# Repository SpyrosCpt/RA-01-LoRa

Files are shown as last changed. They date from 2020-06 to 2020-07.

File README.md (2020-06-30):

# RA-01-LoRa Dev Board

## Features
- Max 15V DC input
- 5V DC USB input
- CP2102 USB interface
- STM32F030RCT6
- 0.96" 128 x 32 OLED
- RA-01 LoRA Module
- LM35 Temperature Sensor
- AT93C46 EEPROM
- 4 Way DIP Switch
- 4 Push Buttons
- STM32 programming by SWD

## Firmware Example Provided
- Press Push Button 1 to Send LoRA Packet, you can change the data to send by editing TestLoraTransmit("packet to send")
- When not transmitting LoRA radio is in Receiver mode and will display any messages receievd
- Temperature Monitoring of LM35 will be displayed on OLED

## Hardware Version 1.1
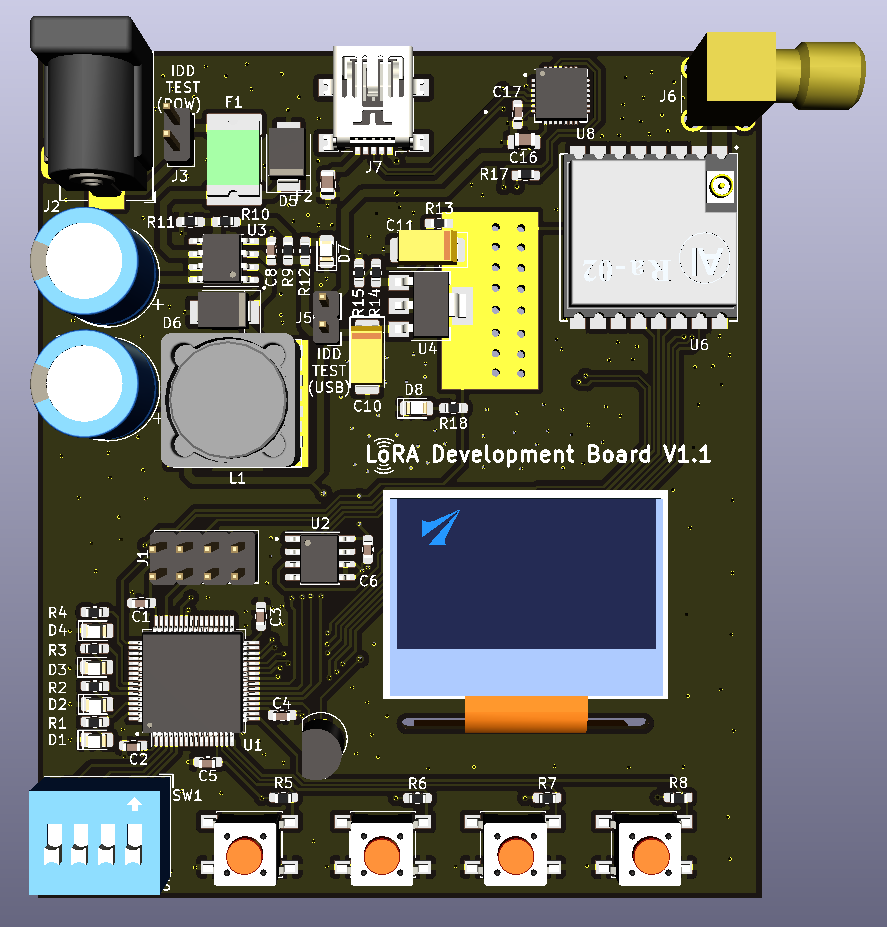
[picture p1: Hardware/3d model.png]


## Firmware Change Log
- Changed frequency down from 915Mhz to 433MHz
- Oled working
- LoRa working
- EEPROM working
- Temp Sensor

## Harware Change Log
- Removed USB protection IC
- Swapped TX and RX lines
- Grounded pin 16 + 17 on OLED connector
- Moved LM34 Vcc from 3.3V to 5V

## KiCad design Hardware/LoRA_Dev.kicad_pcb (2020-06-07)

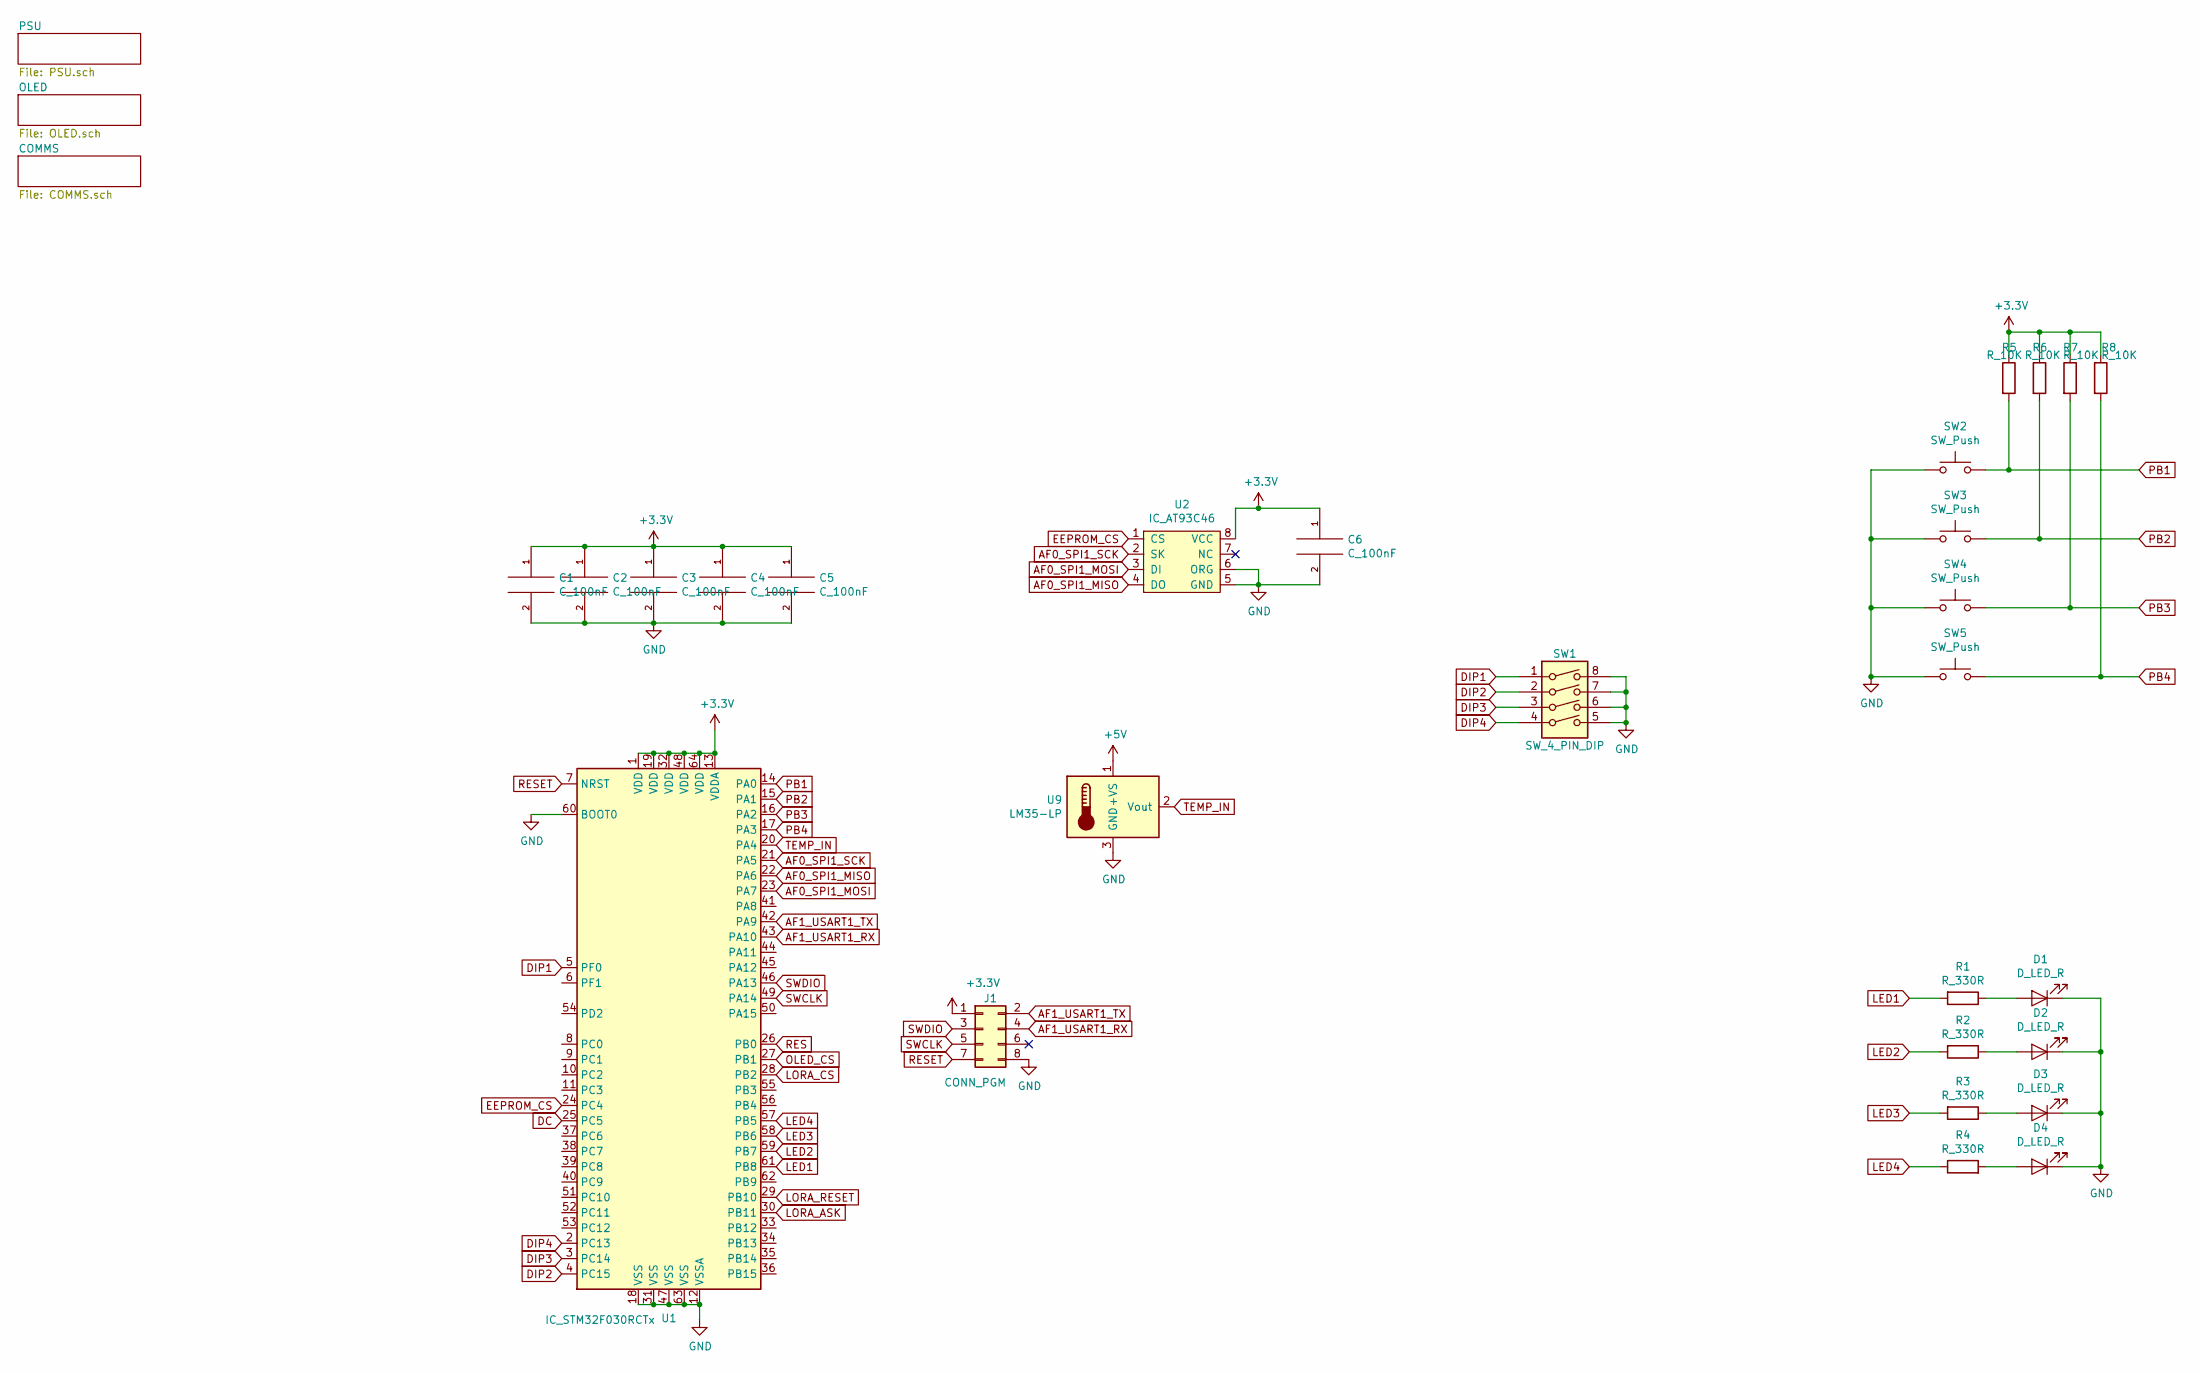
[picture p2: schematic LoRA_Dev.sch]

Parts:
C1, C2, C3, C4, C5, C6: C_100nF; C_0603_1608Metric_Pad1.05x0.95mm_HandSolder
D1, D2, D3, D4: D_LED_R; LED_0805_2012Metric_Pad1.15x1.40mm_HandSolder
J1: CONN_PGM; PinHeader_2x04_P2.54mm_Vertical
R1, R2, R3, R4: R_330R; R_0603_1608Metric_Pad1.05x0.95mm_HandSolder
R5, R6, R7, R8: R_10K; R_0603_1608Metric_Pad1.05x0.95mm_HandSolder
SW1: SW_4_PIN_DIP; SW_DIP_SPSTx04_Slide_9.78x12.34mm_W7.62mm_P2.54mm
SW2, SW3, SW4, SW5: SW_Push; SW_SPST_PTS645
U1: IC_STM32F030RCTx; LQFP-64_10x10mm_P0.5mm
U2: IC_AT93C46; SOIC-8_3.9x4.9mm_P1.27mm
U9: LM35-LP; TO-92

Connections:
+3V3: C1.1, C2.1, C3.1, C4.1, C5.1, C6.1, J1.1, R5.1, R6.1, R7.1, R8.1, U1.1 (VDD), U1.13 (VDDA), U1.19 (VDD), U1.32 (VDD), U1.48 (VDD), U1.64 (VDD), U2.8 (VCC); also elsewhere on the board
+5V: U9.1 (+VS); also elsewhere on the board
AF0_SPI1_MISO: U1.22 (PA6), U2.4 (DO); also elsewhere on the board
AF0_SPI1_MOSI: U1.23 (PA7), U2.3 (DI); also elsewhere on the board
AF0_SPI1_SCK: U1.21 (PA5), U2.2 (SK); also elsewhere on the board
AF1_USART1_RX: J1.4, U1.43 (PA10); also elsewhere on the board
AF1_USART1_TX: J1.2, U1.42 (PA9); also elsewhere on the board
DC: U1.25 (PC5); also elsewhere on the board
DIP1: SW1.1, U1.5 (PF0)
DIP2: SW1.2, U1.4 (PC15)
DIP3: SW1.3, U1.3 (PC14)
DIP4: SW1.4, U1.2 (PC13)
EEPROM_CS: U1.24 (PC4), U2.1 (CS)
GND: C1.2, C2.2, C3.2, C4.2, C5.2, C6.2, D1.1 (K), D2.1 (K), D3.1 (K), D4.1 (K), J1.8, SW1.5, SW1.6, SW1.7, SW1.8, SW2.1, SW3.1, SW4.1, SW5.1, U1.12 (VSSA), U1.18 (VSS), U1.31 (VSS), U1.47 (VSS), U1.60 (BOOT0), U1.63 (VSS), U2.5 (GND), U2.6 (ORG), U9.3 (GND); also elsewhere on the board
LED1: R1.2, U1.61 (PB8)
LED2: R2.2, U1.59 (PB7)
LED3: R3.2, U1.58 (PB6)
LED4: R4.1, U1.57 (PB5)
LORA_ASK: U1.30 (PB11); also elsewhere on the board
LORA_CS: U1.28 (PB2); also elsewhere on the board
LORA_RESET: U1.29 (PB10); also elsewhere on the board
unnamed: D1.2 (A), R1.1
unnamed: D2.2 (A), R2.1
unnamed: D3.2 (A), R3.1
unnamed: D4.2 (A), R4.2
OLED_CS: U1.27 (PB1); also elsewhere on the board
PB1: R5.2, SW2.2, U1.14 (PA0)
PB2: R6.2, SW3.2, U1.15 (PA1)
PB3: R7.2, SW4.2, U1.16 (PA2)
PB4: R8.2, SW5.2, U1.17 (PA3)
RES: U1.26 (PB0); also elsewhere on the board
RESET: J1.7, U1.7 (NRST)
SWCLK: J1.5, U1.49 (PA14)
SWDIO: J1.3, U1.46 (PA13)
TEMP_IN: U1.20 (PA4), U9.2 (Vout)

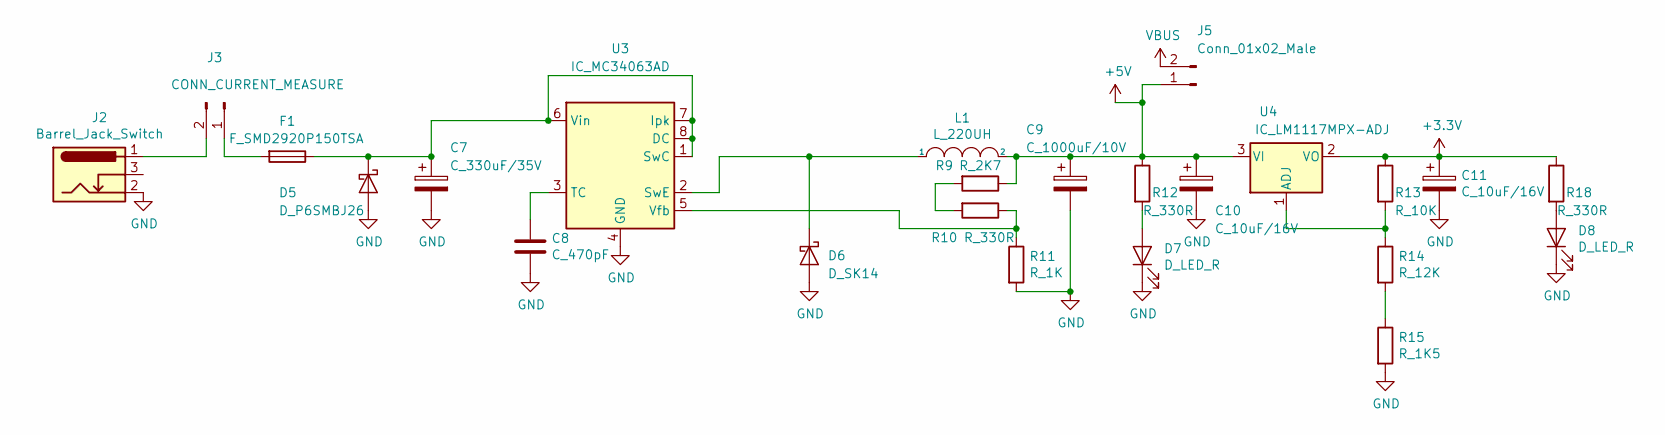
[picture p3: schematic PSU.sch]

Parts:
C7: C_330uF/35V; CP_Radial_D10.0mm_P5.00mm
C8: C_470pF; C_0603_1608Metric_Pad1.05x0.95mm_HandSolder
C9: C_1000uF/10V; CP_Radial_D10.0mm_P5.00mm
C10, C11: C_10uF/16V; CP_EIA-6032-28_Kemet-C_Pad2.25x2.35mm_HandSolder
D5: D_P6SMBJ26; D_SMB
D6: D_SK14; D_SMB
D7, D8: D_LED_R; LED_0805_2012Metric_Pad1.15x1.40mm_HandSolder
F1: F_SMD2920P150TSA; Fuse_2920_7451Metric_Pad2.10x5.45mm_HandSolder
J2: Barrel_Jack_Switch; BarrelJack_Horizontal
J3: CONN_CURRENT_MEASURE; PinHeader_2x01_P2.54mm_Vertical
J5: Conn_01x02_Male; PinHeader_1x02_P2.54mm_Vertical
L1: L_220UH; L_12x12mm_H8mm
R9: R_2K7; R_0603_1608Metric_Pad1.05x0.95mm_HandSolder
R10, R12, R18: R_330R; R_0603_1608Metric_Pad1.05x0.95mm_HandSolder
R11: R_1K; R_0603_1608Metric_Pad1.05x0.95mm_HandSolder
R13: R_10K; R_0603_1608Metric_Pad1.05x0.95mm_HandSolder
R14: R_12K; R_0603_1608Metric_Pad1.05x0.95mm_HandSolder
R15: R_1K5; R_0603_1608Metric_Pad1.05x0.95mm_HandSolder
U3: IC_MC34063AD; SOIC-8_3.9x4.9mm_P1.27mm
U4: IC_LM1117MPX-ADJ; SOT-223-3_TabPin2

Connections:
+3V3: C11.1, R13.1, R18.1, U4.2 (VO); also elsewhere on the board
+5V: C9.1, C10.1, J5.1, L1.2, R9.1, R12.1, U4.3 (VI); also elsewhere on the board
GND: C7.2, C8.2, C9.2, C10.2, C11.2, D5.2 (A), D6.2 (A), D7.1 (K), D8.1 (K), J2.2, R11.2, R15.2, U3.4 (GND); also elsewhere on the board
unnamed: C7.1, D5.1 (K), F1.1, U3.1 (SwC), U3.6 (Vin), U3.7 (Ipk), U3.8 (DC)
unnamed: C8.1, U3.3 (TC)
unnamed: D6.1 (K), L1.1, U3.2 (SwE)
unnamed: D7.2 (A), R12.2
unnamed: D8.2 (A), R18.2
unnamed: F1.2, J3.1
unnamed: J2.1, J3.2
unnamed: R10.1, R11.1, U3.5 (Vfb)
unnamed: R9.2, R10.2
unnamed: R13.2, R14.1, U4.1 (ADJ)
unnamed: R14.2, R15.1
VBUS: J5.2; also elsewhere on the board

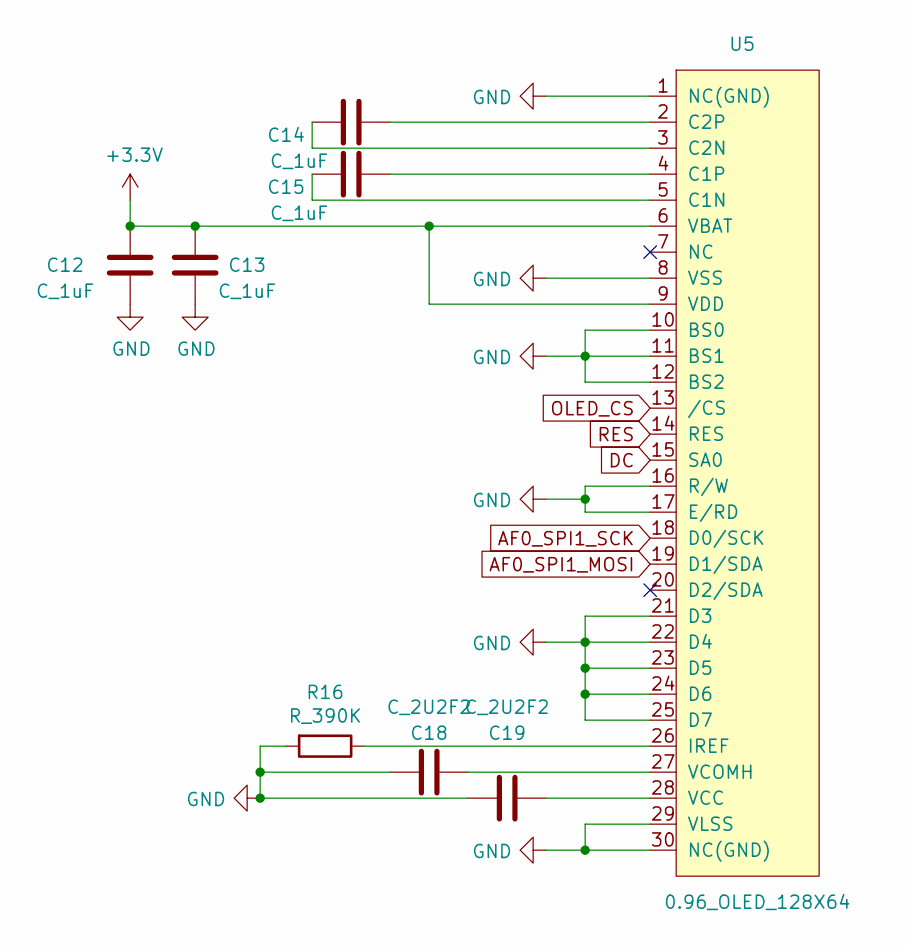
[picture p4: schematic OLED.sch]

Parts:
C12, C13, C14, C15: C_1uF; C_0805_2012Metric_Pad1.15x1.40mm_HandSolder
C18, C19: C_2U2F2; C_0805_2012Metric_Pad1.15x1.40mm_HandSolder
R16: R_390K; R_0603_1608Metric_Pad1.05x0.95mm_HandSolder
U5: 0.96_OLED_128X64; 0.96_OLED

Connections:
+3V3: C12.2, C13.2, U5.6 (VBAT), U5.9 (VDD); also elsewhere on the board
AF0_SPI1_MOSI: U5.19 (D1/SDA); also elsewhere on the board
AF0_SPI1_SCK: U5.18 (D0/SCK); also elsewhere on the board
DC: U5.15 (SA0); also elsewhere on the board
GND: C12.1, C13.1, C18.1, C19.1, R16.2, U5.1 (NC(GND)), U5.8 (VSS), U5.10 (BS0), U5.11 (BS1), U5.12 (BS2), U5.16 (R/W), U5.17 (E/RD), U5.21 (D3), U5.22 (D4), U5.23 (D5), U5.24 (D6), U5.25 (D7), U5.29 (VLSS), U5.30 (NC(GND)); also elsewhere on the board
unnamed: C14.1, U5.2 (C2P)
unnamed: C14.2, U5.3 (C2N)
unnamed: C15.1, U5.4 (C1P)
unnamed: C15.2, U5.5 (C1N)
unnamed: C18.2, U5.27 (VCOMH)
unnamed: C19.2, U5.28 (VCC)
unnamed: R16.1, U5.26 (IREF)
OLED_CS: U5.13 (/CS); also elsewhere on the board
RES: U5.14 (RES); also elsewhere on the board

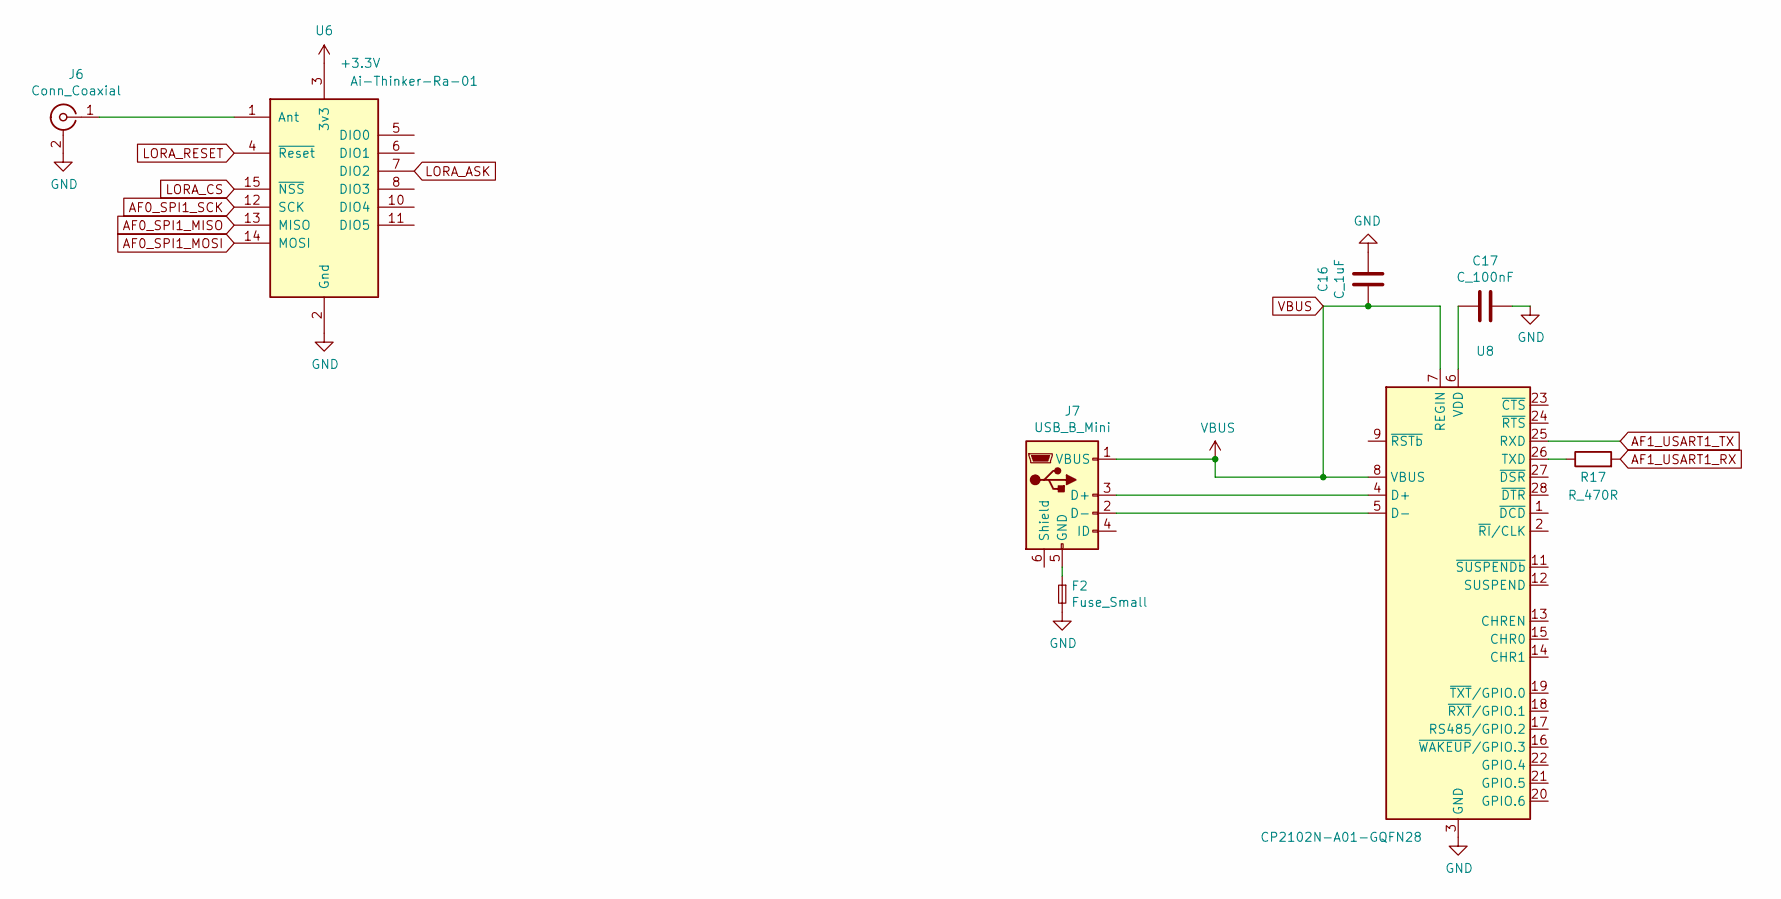
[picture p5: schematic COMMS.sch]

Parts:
C16: C_1uF; C_0805_2012Metric_Pad1.15x1.40mm_HandSolder
C17: C_100nF; C_0603_1608Metric_Pad1.05x0.95mm_HandSolder
F2: Fuse_Small; C_0805_2012Metric
J6: Conn_Coaxial; SMA_Amphenol_132134_Vertical
J7: USB_B_Mini; USB_Mini-B_Lumberg_2486_01_Horizontal
R17: R_470R; R_0603_1608Metric_Pad1.05x0.95mm_HandSolder
U6: Ai-Thinker-Ra-01; Ai-Thinker-Ra-01-LoRa
U8: CP2102N-A01-GQFN28; QFN-28-1EP_5x5mm_P0.5mm_EP3.35x3.35mm

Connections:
+3V3: U6.3 (3v3); also elsewhere on the board
AF0_SPI1_MISO: U6.13 (MISO); also elsewhere on the board
AF0_SPI1_MOSI: U6.14 (MOSI); also elsewhere on the board
AF0_SPI1_SCK: U6.12 (SCK); also elsewhere on the board
AF1_USART1_RX: R17.2; also elsewhere on the board
AF1_USART1_TX: U8.25 (RXD); also elsewhere on the board
GND: C16.1, C17.1, F2.2, J6.2 (Ext), U6.2 (Gnd), U6.9 (Gnd), U6.16 (Gnd), U8.3 (GND), U8.29 (GND); also elsewhere on the board
LORA_ASK: U6.7 (DIO2); also elsewhere on the board
LORA_CS: U6.15 (~NSS); also elsewhere on the board
LORA_RESET: U6.4 (~Reset); also elsewhere on the board
unnamed: C17.2, U8.6 (VDD)
unnamed: F2.1, J7.5 (GND)
unnamed: J6.1 (In), U6.1 (Ant)
unnamed: J7.2 (D-), U8.5 (D-)
unnamed: J7.3 (D+), U8.4 (D+)
unnamed: R17.1, U8.26 (TXD)
VBUS: C16.2, J7.1 (VBUS), U8.7 (REGIN), U8.8 (VBUS); also elsewhere on the board

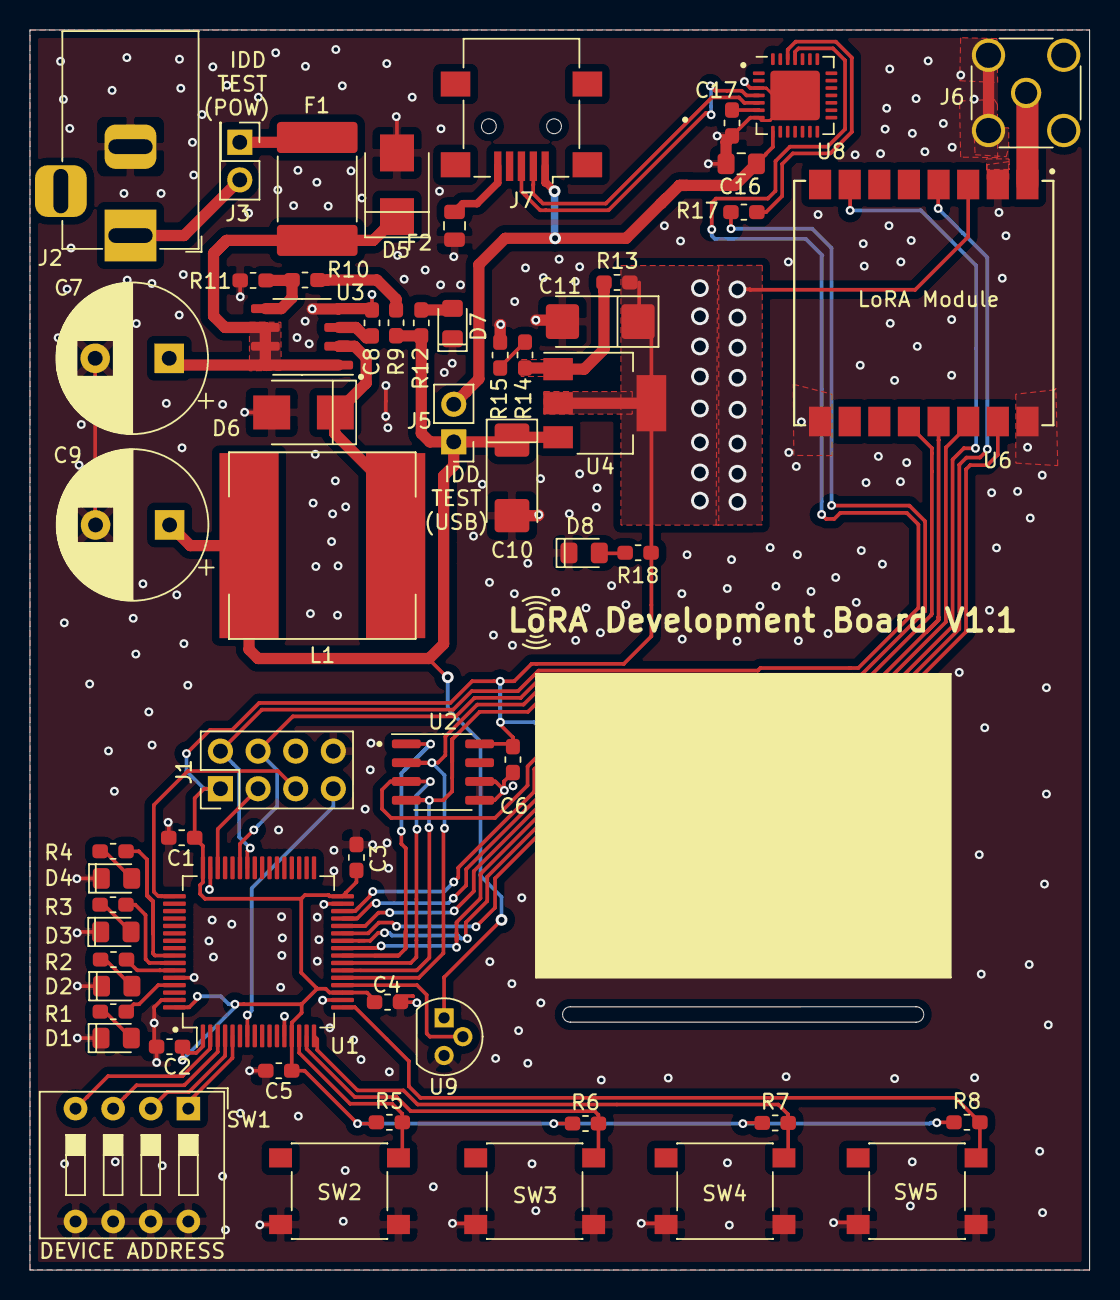
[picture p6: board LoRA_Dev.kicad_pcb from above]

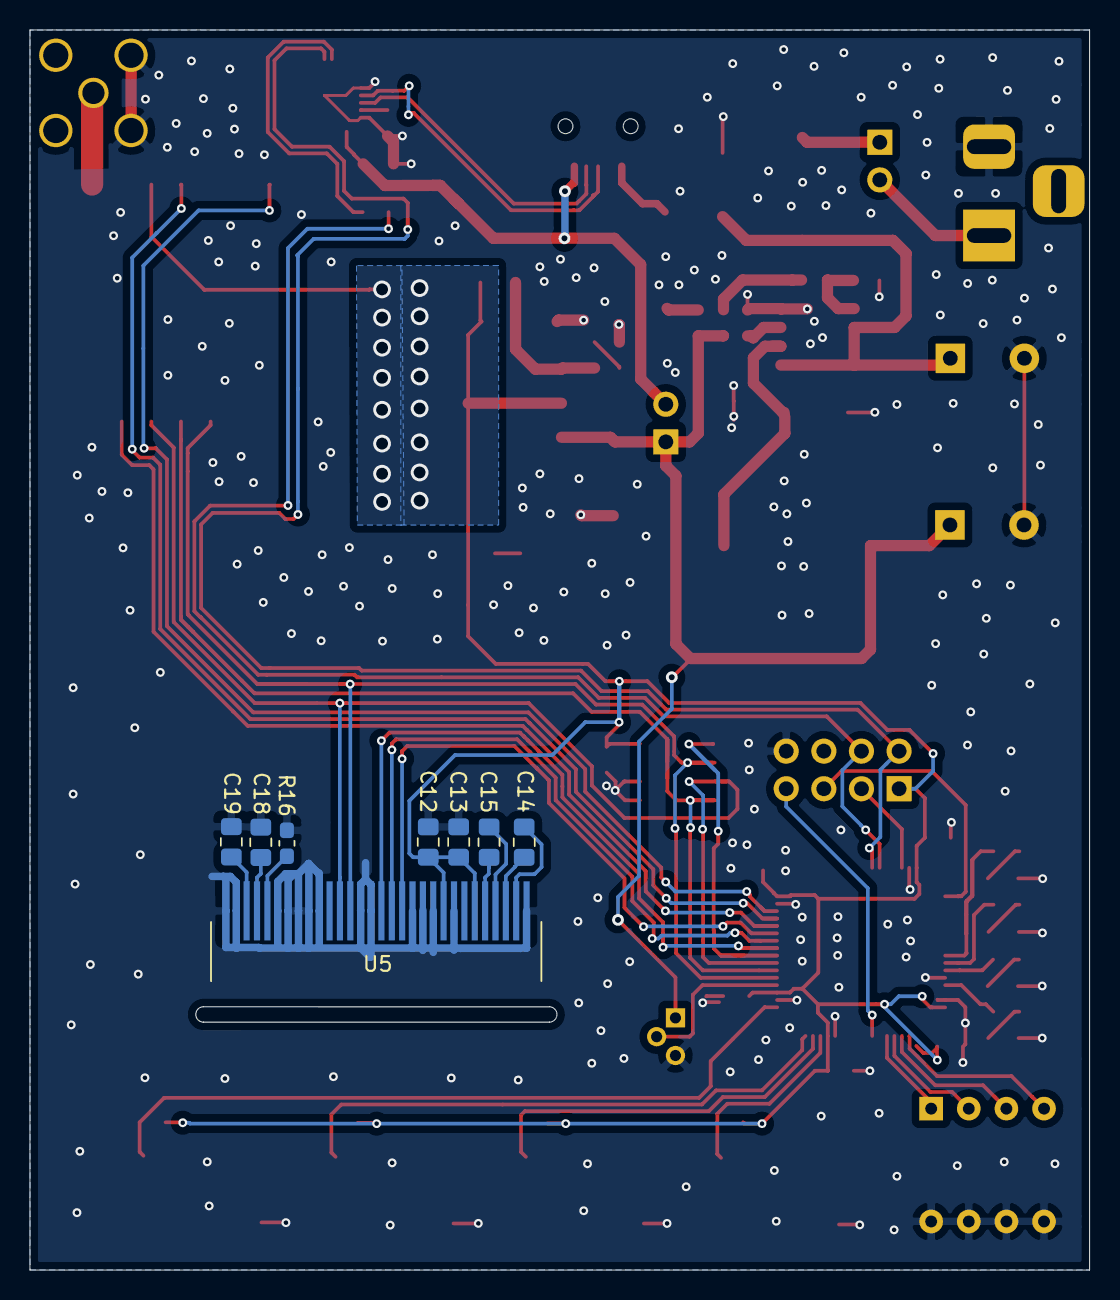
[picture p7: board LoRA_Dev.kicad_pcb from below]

Board: 2 copper layers, 71.5 x 83.7 mm, 67 parts (8 on the bottom side), 60 nets.

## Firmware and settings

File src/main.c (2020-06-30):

#include "preprocessor.h"

#define ADC_TEMPERATURE_CH ADC_CHSELR_CHSEL4

/****************************************/
/***************PROTOTYPES***************/
/****************************************/
void delaymms(int ms);
void delayuus(int us);
void getTemp(void);
void GetDeviceAddress(void);
UI16 GetAnalogVal(UI8 ch);
void GetVddVal(void);
UI16 Get_ADC_Val( void ); 
void DisableADC(void);
void EnableADC(void);
/****************************************/
/***********END OF PROTOTYPES************/
/****************************************/

/****************************************/
/************GLOBAL VARIABLES************/
/****************************************/
static __IO uint32_t systick=0;
volatile UI32 MILLISECS=0;
UI32 adcraw = 0;
UI32 Vdd = 0;
UI16 VddCal = 0;
UI32 TempVdd = 0;
__IO UI16 adcval = 0;
UI16 TemperatureTimer = 0;
UI16 AddressTimer = 0;

/****************************************/
/**********GLOBAL VARIABLES END**********/
/****************************************/

/**
	* @brief 	This is the systick interrupt handler, it fires every 10uS
	* @param 	None
	*	@retval None
	*/
void SysTick_Handler( void )
{
   if( systick ) systick--;
	 if( MILLISECS ) MILLISECS--;
}

/**
* @brief 	This function delays for x microseconds (note: resolution is 10uS)
	* @param 	us - time to wait in us
	*	@retval None
	*/
void delayuus(int us)
{
	systick = us;
	
	while(systick) ;
}

/**
	* @brief 	This function delays for x milliseconds
	* @param 	ms - time to wait in ms
	*	@retval None
	*/
void delaymms(int ms)
{
	MILLISECS = ms*100;
	while(MILLISECS) ;
}

/**
	* @brief 	This is the Timer 3 interrupt handler 
	* @param 	None
	*	@retval None
	*/
void TIM3_IRQHandler( void )
{
	volatile UI8 i;
	if( TIM3->SR & TIM_SR_UIF ) 					/* If UIF flag is set */
  {
		TIM3->SR &= ~TIM_SR_UIF; 					/* Clear UIF flag */
		
		if(TemperatureTimer) TemperatureTimer--;
		if(AddressTimer) AddressTimer--;
  }
}

/**
	* @brief 	This is the Timer 17 Interrupt 
	* @param 	None
	*	@retval None
	*/
void TIM17_IRQHandler( void )
{
if( TIM17->SR & TIM_SR_UIF ) 					/* If UIF flag is set */
 {
		TIM17->SR &= ~TIM_SR_UIF; 					/* Clear UIF flag */
  }
}

/**
	* @brief 	This function enables the ADC
	* @param 	None
	*	@retval None
	*/
void EnableADC(void)
{
	/* (1) Clear the ADRDY bit */
	/* (2) Enable the ADC */
	/* (3) Wait until ADC ready */
	ADC1->ISR |= ADC_ISR_ADRDY; /* (1) */
	ADC1->CR |= ADC_CR_ADEN; /* (2) */
	if ((ADC1->CFGR1 & ADC_CFGR1_AUTOFF) == 0)
	{
		while ((ADC1->ISR & ADC_ISR_ADRDY) == 0) /* (3) */
		{
		/* For robust implementation, add here time-out management */
		}
	}
}

/**
	* @brief 	This function disables the ADC
	* @param 	none		  
	* @retval none
	*/
void DisableADC(void)
{
	/* (1) Ensure that no conversion on going */
	/* (2) Stop any ongoing conversion */
	/* (3) Wait until ADSTP is reset by hardware i.e. conversion is stopped */
	/* (4) Disable the ADC */
	/* (5) Wait until the ADC is fully disabled */
	if ((ADC1->CR & ADC_CR_ADSTART) != 0) /* (1) */
	{
		ADC1->CR |= ADC_CR_ADSTP; /* (2) */
	}
	while ((ADC1->CR & ADC_CR_ADSTP) != 0) /* (3) */
	{
	/* For robust implementation, add here time-out management */
	}
	ADC1->CR |= ADC_CR_ADDIS; /* (4) */
	while ((ADC1->CR & ADC_CR_ADEN) != 0) /* (5) */
	{
	/* For robust implementation, add here time-out management */
	}
}

/**
	* @brief 	This function gets 60 values from the ADC and takes an average of them
	* @param 	None
	*	@retval Val16 - the averaged ADC value
	*/
UI16 Get_ADC_Val( void ) 
{ 
	UI8 samples = 0;                					    /* Each sample takes 1uS so we should get this over and done with in about 100uS */
	UI8 NumSamples = 60;
	UI32 adcreg=0;
	UI16 Val16;
	
	ADC1->CR |= ADC_CR_ADSTART;                 /* Start conversion */
	for( samples = 0; samples < NumSamples; samples++ )   /* Take 5 samples and add them together */
	{
		
		while( ( ADC1->ISR & ADC_ISR_EOC ) == 0 );  /* Wait for conversion to finish */
		
		adcreg += ADC1->DR;								        /* Get value from ADC data reg */
	}
	adcreg/=NumSamples;											    /* Get an average off all the samples */	
	Val16=adcreg;
		
	return Val16;

}

/**
	* @brief 	This function gets the actual value of Vdd using the stored calibration value
	* @param 	None
	*	@retval None
	*/
void GetVddVal(void)
{
	adcraw = 0;

	DisableADC();
	ADC1->CHSELR = 0x00000000;
	ADC1->CHSELR |= ADC_CHSELR_CHSEL17;                         /* Set ADC channel to Vref (CH17) */
	EnableADC();
	
	adcraw = Get_ADC_Val();

	Vdd = 3300UL * (*VREFINT_CAL) / adcraw;         /*Calculate actual Vdd value*/
	
	PrintfP("\nVdd = %d", Vdd);
	PrintfP("\nADC = %d", adcraw);

	if(Vdd>3500) Vdd=3300; //sanity                 /* Will sanitize if values are wonky */
	if(Vdd<3000) Vdd=3300;
	
}

/**
	* @brief 	This function sets and enables an analog channel and returns an ADC value from the channel
	* @param 	ch - channel to set
	*	@retval adcval - ADC value to return
	*/
UI16 GetAnalogVal(UI8 ch)
{
	adcval = 0;

	DisableADC();
	
	ADC1->CHSELR = 0x00000000;
	ADC1->CHSELR |= ch;                         /* Set ADC channel to Vref (CH17) */

	EnableADC();
	
	adcval = Get_ADC_Val();

	return adcval;
}

/**
	* @brief 	This function reads the position from the DIP switch and returns the value as an address
	* @param 	None
	*	@retval None
	*/
void GetDeviceAddress(void)
{
	UI8 DIPS[4] = {0,0,0,0};
	UI8 Address = 0;
	UI8 i = 0;
	
	if(!AddressTimer)
	{
		if(DIP0_READ() == 0) DIPS[3] = 1;
		if(DIP1_READ() == 0) DIPS[2] = 1;
		if(DIP2_READ() == 0) DIPS[1] = 1;
		if(DIP3_READ() == 0) DIPS[0] = 1;
		
		for(i = 0; i < 4; i++)
		{
			if(DIPS[i] == 1) Address |= (1<<i);
		}
		PrintOLED(0,0, "Address = %d", Address);
		AddressTimer = 100;
	}
}

/**
	* @brief 	This function gets a value from the LM35 or LM34 sensor (choose this in preprocessor.h)
	* @param 	None
	*	@retval None
	*/
void getTemperature(void)
{
	UI32 temp = 0;
	float temp2 = 0;
	
	if(TemperatureTimer == 0)
	{
		temp = GetAnalogVal(ADC_TEMPERATURE_CH);
		
		#if (TEMP_SENSOR == LM34)
		temp2 = temp*0.088;
		temp2 -= 32;
		temp2 *= 0.55555;
		#else 
		temp2 = (temp*Vdd);
		temp2 /= 4095;
		temp2/=10;
		#endif
		
		PrintOLED(0, 6, "Temp = %dC", (UI16)temp2);
		
		TemperatureTimer = 100;
	}
}

int main( void )
{	
	Setup();                          																			 /* Setup the hardware and peripherals */  
	
	while(1)
	{
		if(PB0_READ() == 0) TestLoRaTransmitter("Hello World"); /* Send out a packet */
	  
		getTemperature();                                              /* Get value from temperature sensor */
		GetDeviceAddress();                                     /* Check the DIP switches */
		TestLoRaReceiver();                                     /* Check and see if any incomming packets */
	}
}

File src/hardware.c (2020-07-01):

#include "preprocessor.h"

/**
	* @brief 	This function sets up a GPIO
	* @param 	*PORT - the port (GPIOA, GPIOB etc)
	*         pin - pin to use 0 - 15
	*					direction - INPUT or OUTPUT
	*					type - PushPull, OpenDrain
	*					speed - LoSpeed, MedSpeed, HiSpeed
	*					pull - PullUp, PullDwn, NoPull
	*					state - SET, RESET, NONE
	*	@retval None
	*/
void Set_Pin( GPIO_TypeDef * PORT, uint8_t pin, uint8_t direction, uint8_t type, uint8_t speed, uint8_t pull, uint8_t state )
{
	Set_Mode( PORT, pin, direction );
	Set_Type( PORT, pin, type );
	Set_Speed( PORT, pin, speed );
	Set_Pull( PORT, pin, pull );
	
	if( state == 1 ) PORT->BSRR |= ( 1 << pin );
	else if( state == 2 ) PORT->BRR |= ( 1 << pin );
}
void Set_Mode( GPIO_TypeDef * PORT, uint8_t pin, uint8_t direction ) 
{
	PORT->MODER |= ( direction<< ( pin * 2 ) );
}

void Set_Type( GPIO_TypeDef * PORT, uint8_t pin, uint8_t type )
{
	PORT->OTYPER |= ( type<<pin );
}

void Set_Speed(GPIO_TypeDef * PORT, uint8_t pin, uint8_t speed )
{
	PORT->OSPEEDR |= ( speed<<( pin * 2 ) );
}

void Set_Pull(GPIO_TypeDef * PORT, uint8_t pin, uint8_t pull )
{
	PORT->PUPDR |= ( pull<< ( pin * 2 ) );
}

/**
	* @brief 	This function sets up the GPIO
	* @param 	None
	*	@retval None
	*/
void Ports_Setup( void )
{
	Set_Pin(GPIOB,  5, OUTPUT, PushPull, HiSpeed, NoPull, SET);
	Set_Pin(GPIOB,  6, OUTPUT, PushPull, HiSpeed, NoPull, SET);
	Set_Pin(GPIOB,  7, OUTPUT, PushPull, HiSpeed, NoPull, SET);
	Set_Pin(GPIOB,  8, OUTPUT, PushPull, HiSpeed, NoPull, SET);

	Set_Pin(GPIOA,  0, INPUT, PushPull, HiSpeed, NoPull, NONE);
	Set_Pin(GPIOA,  1, INPUT, PushPull, HiSpeed, NoPull, NONE);
	Set_Pin(GPIOA,  2, INPUT, PushPull, HiSpeed, NoPull, NONE);
	Set_Pin(GPIOA,  3, INPUT, PushPull, HiSpeed, NoPull, NONE);
	
	Set_Pin(GPIOC,  13, INPUT, PushPull, HiSpeed, PullUp, NONE);
	Set_Pin(GPIOC,  14, INPUT, PushPull, HiSpeed, PullUp, NONE);
	Set_Pin(GPIOC,  15, INPUT, PushPull, HiSpeed, PullUp, NONE);
	Set_Pin(GPIOF,  0, INPUT, PushPull, HiSpeed, PullUp, NONE);
	
	Set_Pin(GPIOC,  4, OUTPUT, PushPull, HiSpeed, NoPull, RESET); //EEPROM_CS
	
	Set_Pin(GPIOA,  5, OUTPUT, PushPull, HiSpeed, NoPull, RESET); //CLK
	Set_Pin(GPIOA,  6, INPUT, PushPull, HiSpeed, NoPull, NONE);   //MISO
	Set_Pin(GPIOA,  7, OUTPUT, PushPull, HiSpeed, NoPull, RESET); //MOSI*/
	
	Set_Pin(GPIOB,  1, OUTPUT, PushPull, HiSpeed, NoPull, SET); //OLED_CS
	Set_Pin(GPIOC,  5, OUTPUT, PushPull, HiSpeed, NoPull, NONE); //OLED_DC
	Set_Pin(GPIOB,  0, OUTPUT, PushPull, HiSpeed, NoPull, SET); //OLED_RESET
	
	Set_Pin(GPIOB,  2, OUTPUT, PushPull, HiSpeed, NoPull, SET); //LORA_CS
	Set_Pin(GPIOB,  11, OUTPUT, PushPull, HiSpeed, NoPull, RESET); //LORA_CS
	Set_Pin(GPIOB,  10, OUTPUT, PushPull, HiSpeed, NoPull, SET); //LORA_RESET
}

/**
	* @brief 	This function sets up the Timer3 (1ms resolution)
	* @param 	None
	*	@retval None
	*/
void TIM3_Setup(void)//1ms resolution
{
	RCC->APB1ENR |= RCC_APB1ENR_TIM3EN;
	TIM3->PSC = (uint16_t) 24000 - 1;//23999;	        // Set prescaler to 24 000 (PSC + 1)
	TIM3->ARR = (uint16_t) 2 - 1;	          // Auto reload value 1000
	TIM3->DIER = TIM_DIER_UIE; // Enable update interrupt (timer level)
	TIM3->CR1 |= TIM_CR1_CEN;   // Enable timer
	NVIC_EnableIRQ( TIM3_IRQn ); // Enable interrupt from TIM3 (NVIC level)
}

/**
	* @brief 	This function sets up the Timer17 (10us resolution)
	* @param 	None
	*	@retval None
	*/
void TIM17_Setup(void)//10us resolution
{
	RCC->APB2ENR |= RCC_APB2ENR_TIM17EN;
	TIM17->PSC = (uint16_t) 8 - 1;//23999;	        // Set prescaler to 24 000 (PSC + 1)
	TIM17->ARR = (uint16_t) 2 - 1;//10-1;//10 - 1;	          // Auto reload value 1000
	TIM17->DIER = TIM_DIER_UIE; // Enable update interrupt (timer level)
	TIM17->CR1 &= ~TIM_CR1_CEN;   // Enable timer
	NVIC_EnableIRQ( TIM17_IRQn ); // Enable interrupt from TIM3 (NVIC level)
}

/**
	* @brief 	This function sets up systick (10uS)
	* @param 	None
	*	@retval None
	*/
void SysTick_Init(void) 
{
	/****************************************
	 *SystemFrequency/1000      1ms         *
	 *SystemFrequency/100000    10us        *
	 *SystemFrequency/1000000   1us         *
	 *****************************************/
	while ((SysTick_Config(SystemCoreClock / 100000)) != 0) {
	} // One SysTick interrupt now equals 1us

} 


/**
	* @brief 	This function sets up the USART at baud 115200
	* @param 	None
	*	@retval None
	*/
#if DEBUG
void UART_Setup(UI32 baud)
{
	// Enable GPIOA clock
	RCC->AHBENR |= RCC_AHBENR_GPIOAEN;

	// Configure PA9 and PA10 as Alternate function
	GPIOA->MODER &= ~(GPIO_MODER_MODER9_Msk | GPIO_MODER_MODER10_Msk);
	GPIOA->MODER |= (0x02 <<GPIO_MODER_MODER9_Pos) | (0x02 <<GPIO_MODER_MODER10_Pos);

	// Set PA9 and PA10 to AF1 (USART1)
	GPIOA->AFR[1] &= ~(0x00000FF0);
	GPIOA->AFR[1] |=  (0x00000110);

	// Enable USART1 clock
	RCC -> APB2ENR |= RCC_APB2ENR_USART1EN;

	// Clear USART1 configuration (reset state)
	// 8-bit, 1 start, 1 stop, CTS/RTS disabled
	USART1->CR1 = 0x00000000;
	USART1->CR2 = 0x00000000;
	USART1->CR3 = 0x00000000;

	// Select PCLK (APB1) as clock source
	// PCLK -> 48 MHz
	RCC->CFGR3 &= ~RCC_CFGR3_USART1SW_Msk;
	  RCC->CFGR3 |= RCC_CFGR3_USART1SW_0 | RCC_CFGR3_USART1SW_1;
	// Baud Rate = 115200
	// With OVER8=0 and Fck=48MHz, USARTDIV =   48E6/115200 = 416.6666
	// BRR = 417 -> Baud Rate = 115107.9137 -> 0.08% error
	//
	// With OVER8=1 and Fck=48MHz, USARTDIV = 2*48E6/115200 = 833.3333
	// BRR = 833 -> Baud Rate = 115246.0984 -> 0.04% error (better)

	USART1->CR1 |= USART_CR1_OVER8;
	USART1->BRR = 833;//139;//833;//139;//833;//694;// 139;//833;

	// Enable both Transmitter and Receiver
	USART1->CR1 |= USART_CR1_TE | USART_CR1_RE;

	// Enable USART2
	USART1->CR1 |= USART_CR1_UE;
	
	NVIC_SetPriority(USART1_IRQn, 0);
	/* Enable RTC interrupt */
  NVIC_EnableIRQ(USART1_IRQn);
}
#endif
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

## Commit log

2020-05-29 added internal Vdd measurement for adc calibration
2020-05-30 Fixed USB, Temp sensor and OLED
    [COMMS.sch, LoRA_Dev.kicad_pcb, LoRA_Dev.sch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]
2020-06-07 font support added, bugs fixed
    [hardware.c, main.c]
2020-06-18 Add files via upload
    added 3d image of board
